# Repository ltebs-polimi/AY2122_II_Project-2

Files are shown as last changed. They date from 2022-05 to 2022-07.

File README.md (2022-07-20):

# ELECTRONIC TECHNOLOGIES AND BIOSENSORS LABORATORY, a.a. 2021/22

# Project 2 - Colombo L., D'Andrea M.

## Objective of the project

The objective of the project is to design and develop a system able to perform glucose monitoring using PSoC 5 as a potentiostat. Internal subdivision of the repository is as following:

- Case: contains the .stl files for the case design and printing
- Documents: contains all the bibliography related to the project and the datasheets of the hardware components
- Group2.cydsn: backup folder containing only the code related to glucose measurement, peripherals not included. **It is not to be intended as the folder of the whole project**
- PCB: contains schematic and board files for the PCB of the device
- Presentations: contains images of the project and final presentation
- Project_design: folder of the actual project
- PYTHON GUI: folder containing python scripts for the GUI
- Regression: folder containing the regression script used to find a calibration line and related images

**To open and run the project, open the Project_ETBL.cywrk file**

## Features implemented

Besides being capable of performing glucose measurements, the device hardware includes:

- RTC (DS3231): for real time tracking
- Bluetooth BR/EDR module (HC-05): for wireless communication
- External battery
- OLED screen (SSD1306 by Adafruit): to visualize data when GUI is not active
- External EEPROM (24LC512 by MicroChip): to store measurements

The assembled device and PCB are in the following images:
<br>

<p align="center">
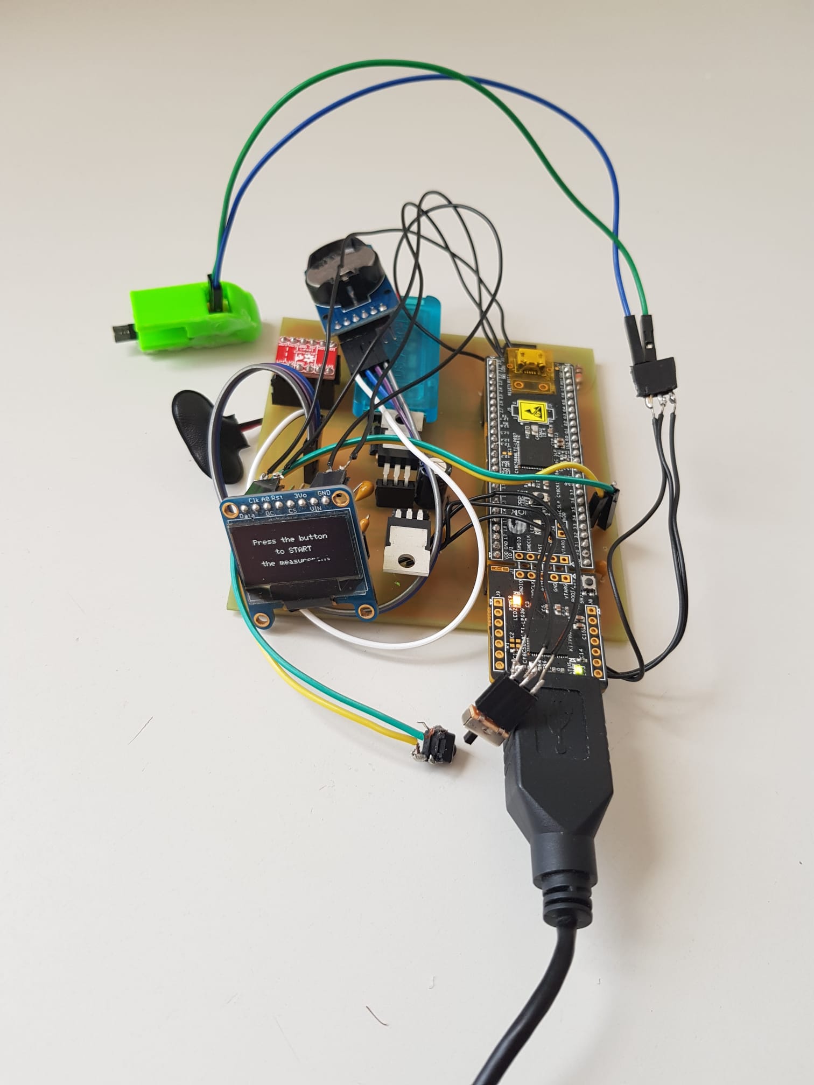
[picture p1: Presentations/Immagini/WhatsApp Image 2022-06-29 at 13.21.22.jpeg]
PCB

</p>
<br><br>

<br>

<p align="center">
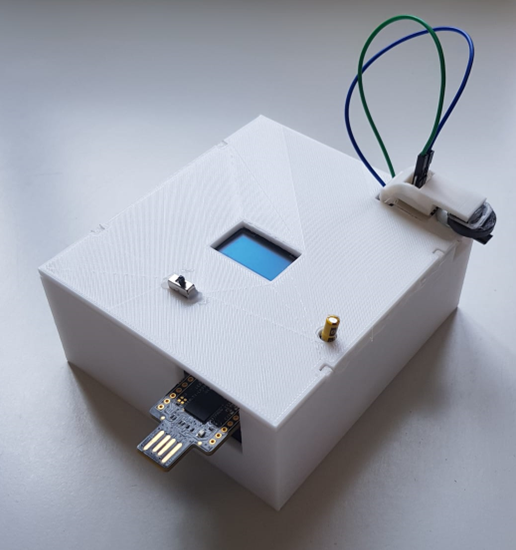
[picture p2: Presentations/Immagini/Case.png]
DEVICE

</p>
<br><br>

## PSoC code
The PSoC code is composed by:

- A global switch case handling the passage between the different OLED screens, up to the "Press the button to START the measurement" screen

- When the hardware button is pressed, the code automatically fetches potential values from the EEPROM and starts and amperometry scan. Basically "adcDacInterrupt" scans
a look-up table and sets the values to the DAC. At the same time the "adcAmpInterrupt" converts the values read by the ADC into current. In the end a glucose 
concentration value is retrieved by means of a proper calibration curve and the result is shown on the OLED screen.

- In case the GUI is started, the code allows to have a connection to the GUI and all the possible commands are managed. Among the different possibilities:
    - cyclic voltammetry (CV): another look up table is scanned by "dacInterrupt" and the "adcInterrupt" convertes the ADC readings into current. These values are sent to the GUI via bluetooth
    - chronoamperometry (CA): same as described before but in this case the current values are sent via bluetooth to the GUI
    - measurements history: measurements which were saved into the EEPROM (date, time and glucose value) at the end of a CA, are sent to the GUI via bluetooth

**see "GUI code" for further details**

## GUI code
The GUI is based on 3 different screens:

- first_screen.py: it allows to select between a user and a clinician

- user_screen.py:
    - Automatic COM port detection by sending a proper command to the PSoC and waiting for the expected answer
    - By pressing the "START MEASUREMENT" button, only a chronoamperometry will be started by sending a proper command to the psoc. The two ISRs needed for the chronoamperometry will be started. Finally the result of the measurement is displayed

- clinician_screen.py: 
    - Automatic COM port detection by sending a proper command to the PSoC and waiting for the expected answer
    - First tab (cyclic voltammetry): it is possible to setup all the required parameters for a cyclic voltammetry. Then it allows to visualize a real-time
    graph by pressing "DRAW"
    - Second tab (chronoamperometry): The clinician can decide to fetch a value of potential from the EEPROM or to start a CA based on the peak of potential identified 
    by the previous cyclic voltammetry. In both cases the real-time graph is shown
    - Third screen (Data visualization): it displays the result of the chronoamperometry scan, in terms of glucose concentration
    - Fourth tab (History): it allows to check the three latest measurements taken by the device. There is also the indication about the date and the time at which the 
    measurements have been taken

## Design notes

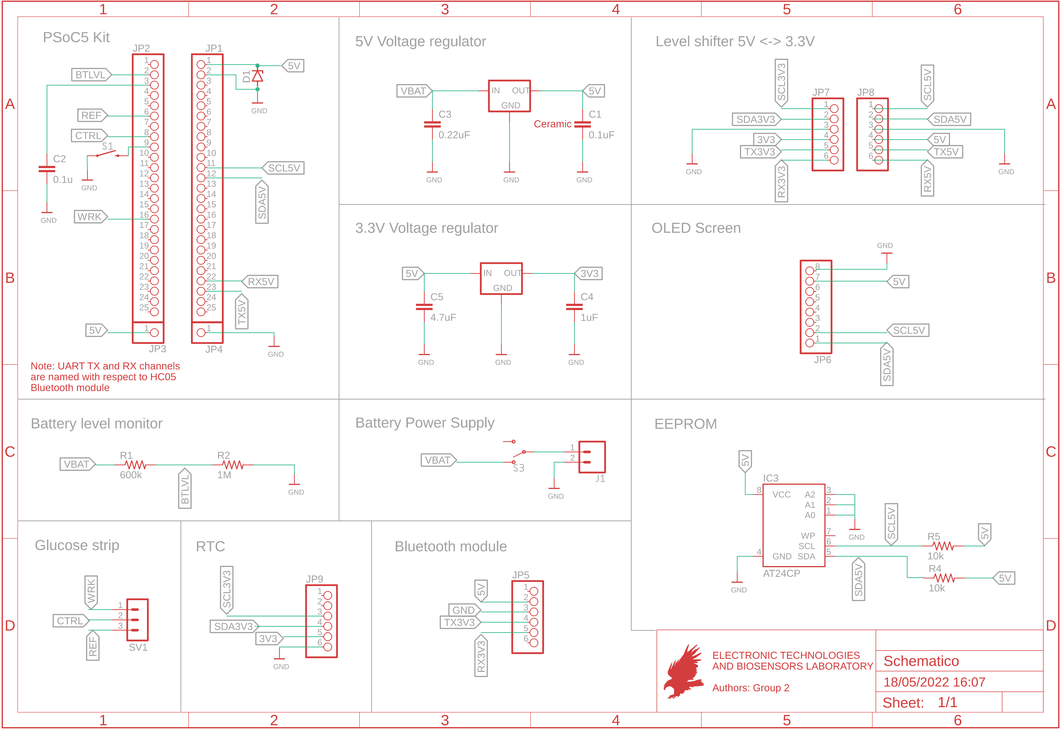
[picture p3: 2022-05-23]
PCB/schematic.png

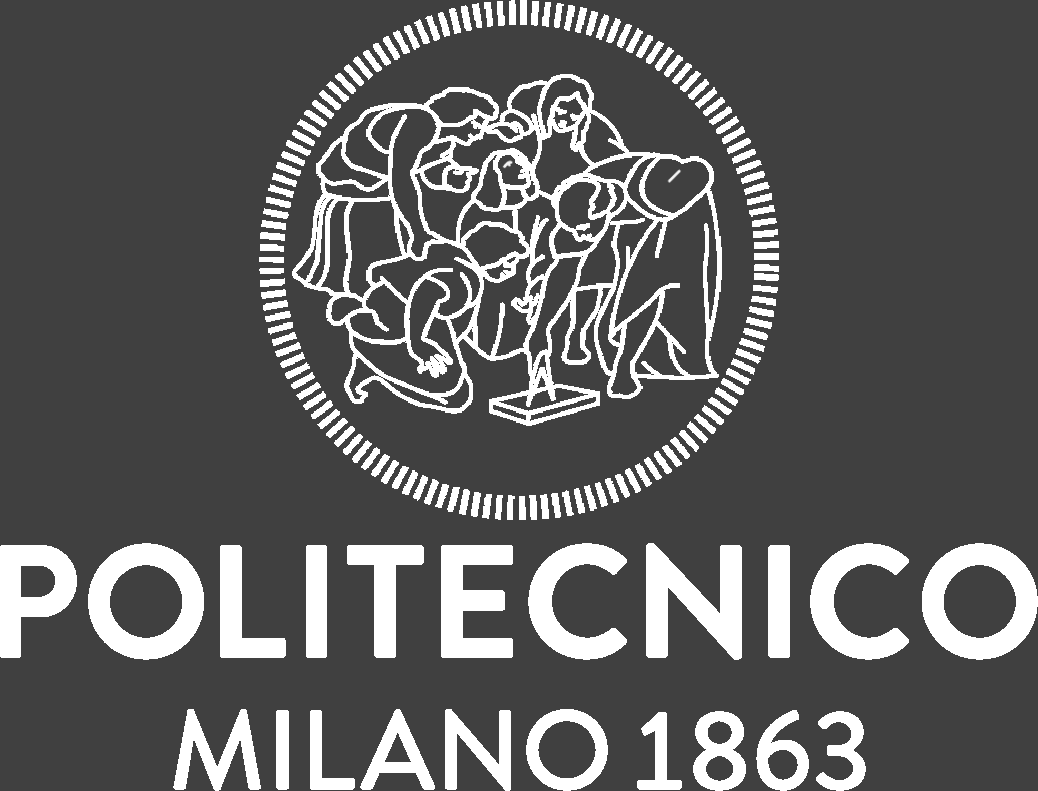
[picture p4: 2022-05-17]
PYTHON GUI/cropped-POLIMI-bianco.png

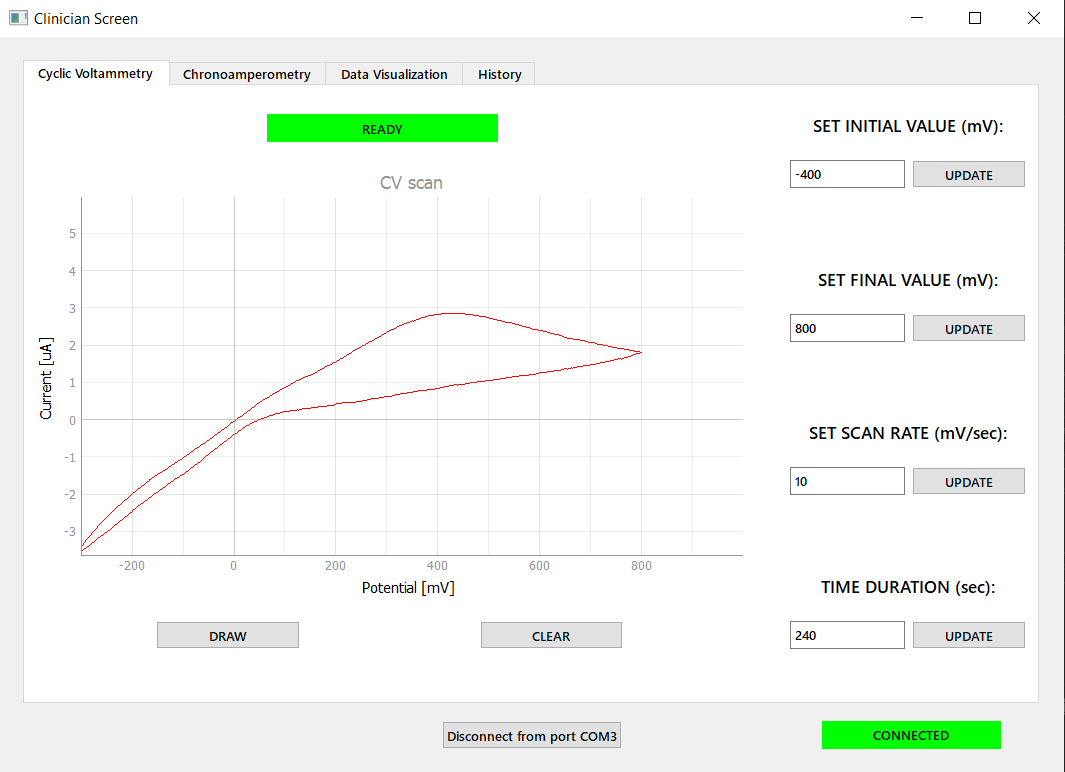
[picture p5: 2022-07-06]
Presentations/Immagini/115-CV.PNG

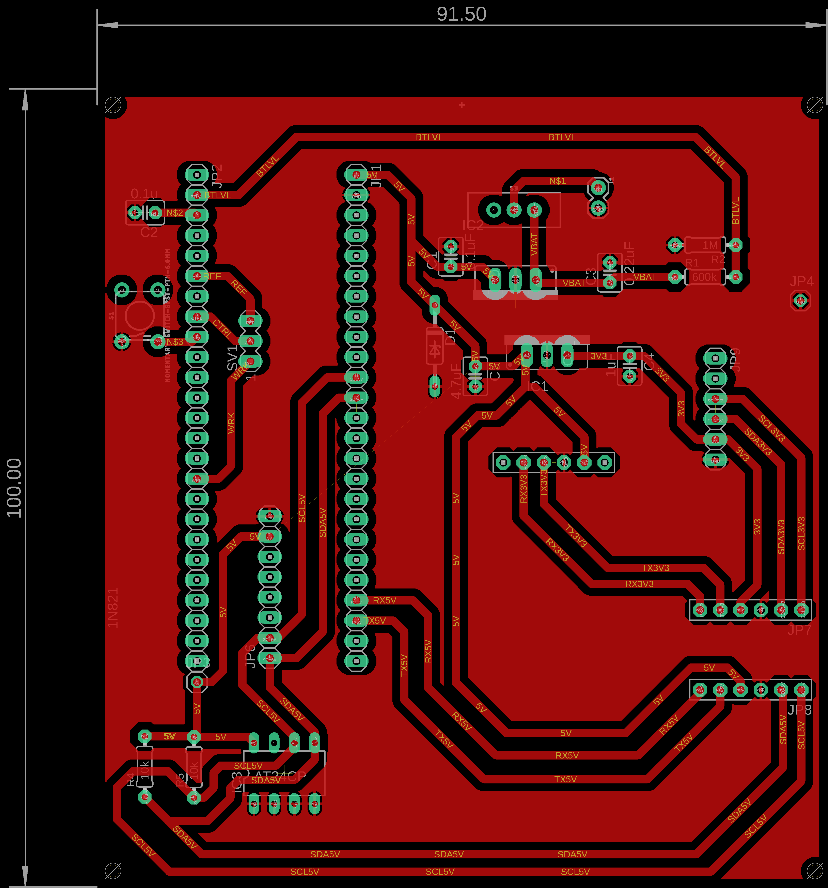
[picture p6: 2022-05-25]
PCB/pcb-1.png

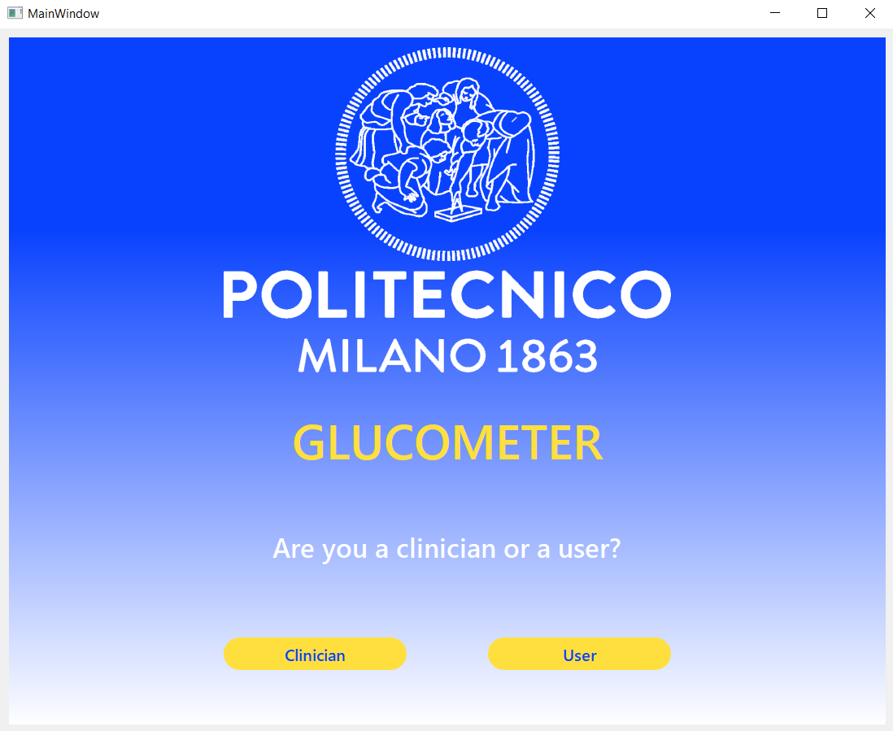
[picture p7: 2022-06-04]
Presentations/Immagini/first_screen.PNG

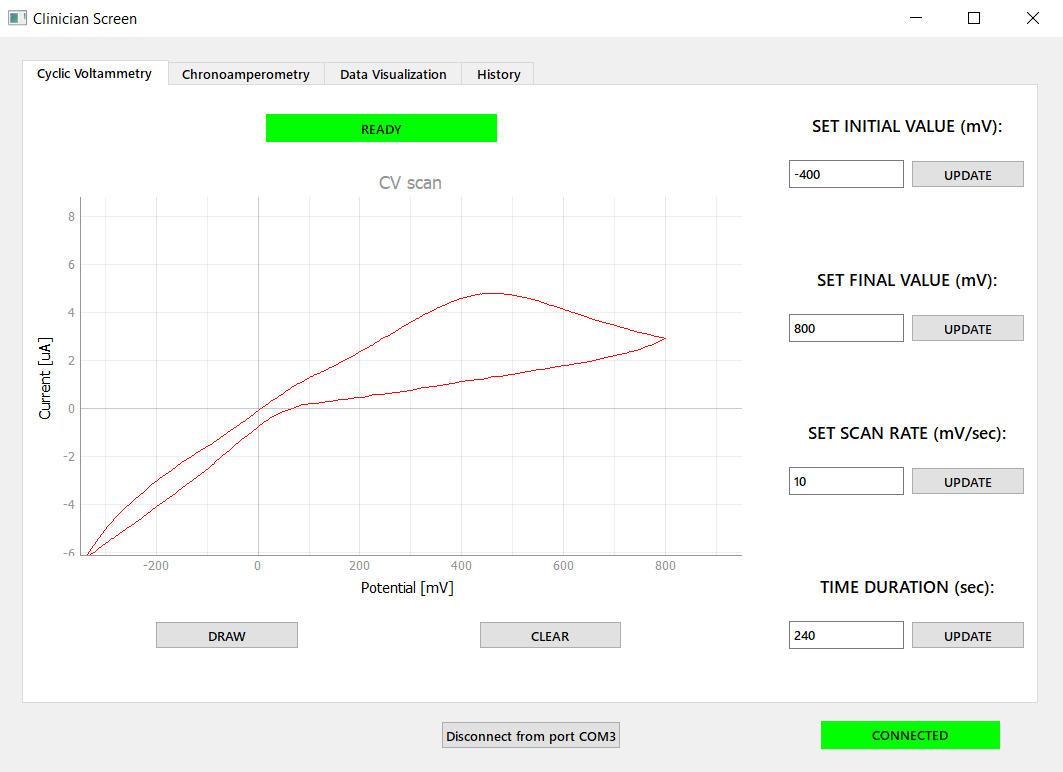
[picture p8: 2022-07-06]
Presentations/Immagini/150-CV.PNG

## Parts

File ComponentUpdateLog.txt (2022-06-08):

Last Modified Date & Time: 06/08/2022 13:05:44

Group2: TopDesign.cysch
	ADC_SigDel [v3.20] to [v3.30]
	isr_adc [v1.70] to [v1.71]
	isr_adcAmp [v1.70] to [v1.71]
	isr_dac [v1.70] to [v1.71]

Project_design: TopDesign.cysch
	ADC_SigDel [v3.20] to [v3.30]
	isr_adc [v1.70] to [v1.71]
	isr_adcAmp [v1.70] to [v1.71]
	isr_dac [v1.70] to [v1.71]

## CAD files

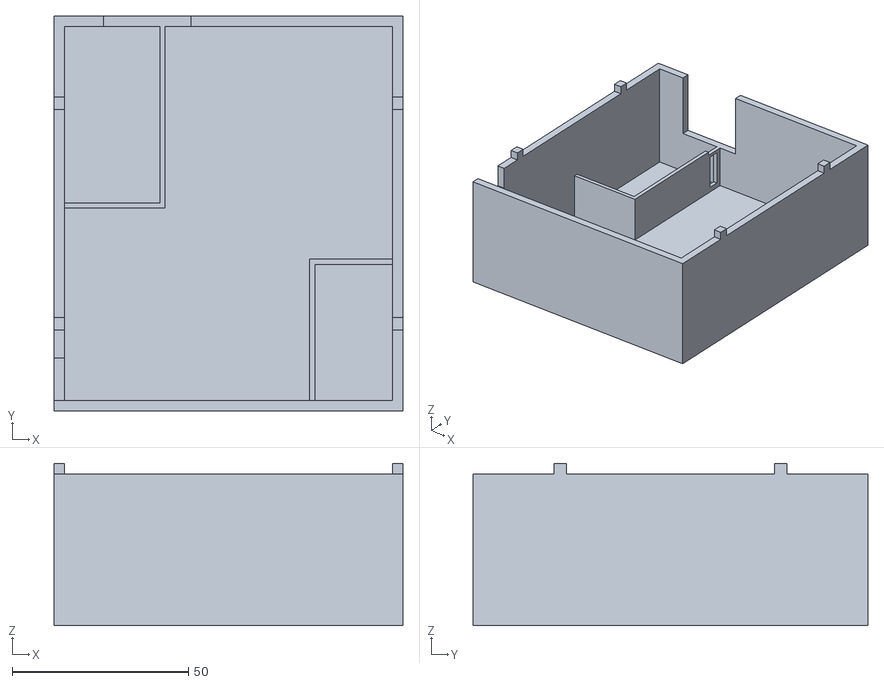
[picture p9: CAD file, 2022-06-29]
Case/Case_ETBL v25.stl
99.0 x 112.0 x 46.0

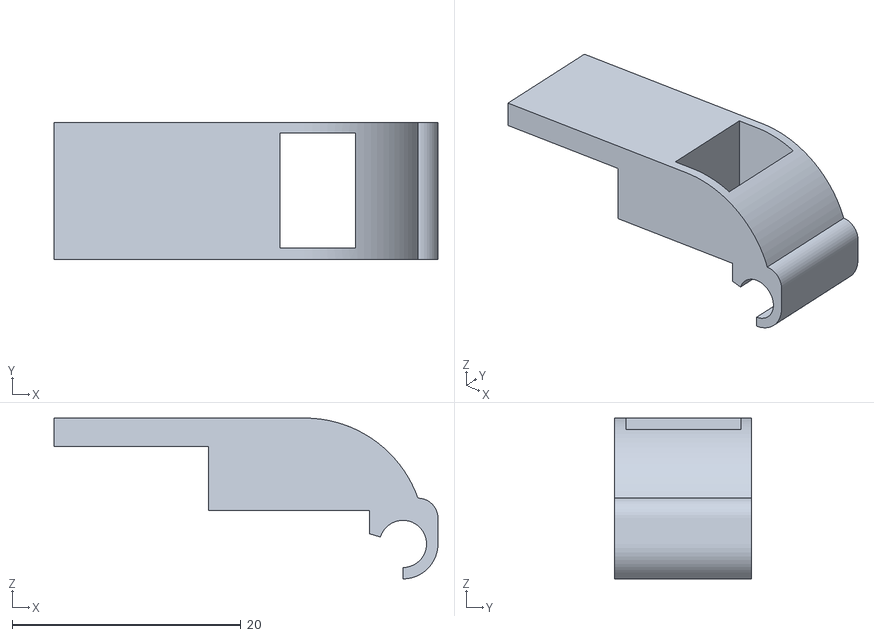
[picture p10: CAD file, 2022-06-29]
Case/Glucometer_clip_top v12.stl
33.6 x 12.0 x 14.1

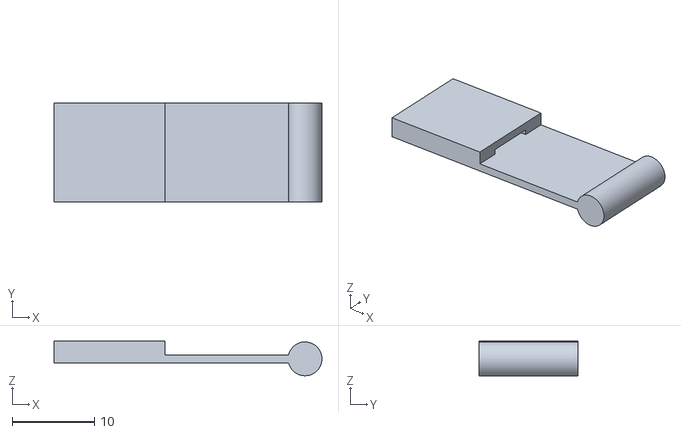
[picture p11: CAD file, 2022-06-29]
Case/Glucometer_clip v12.stl
32.6 x 12.0 x 4.21

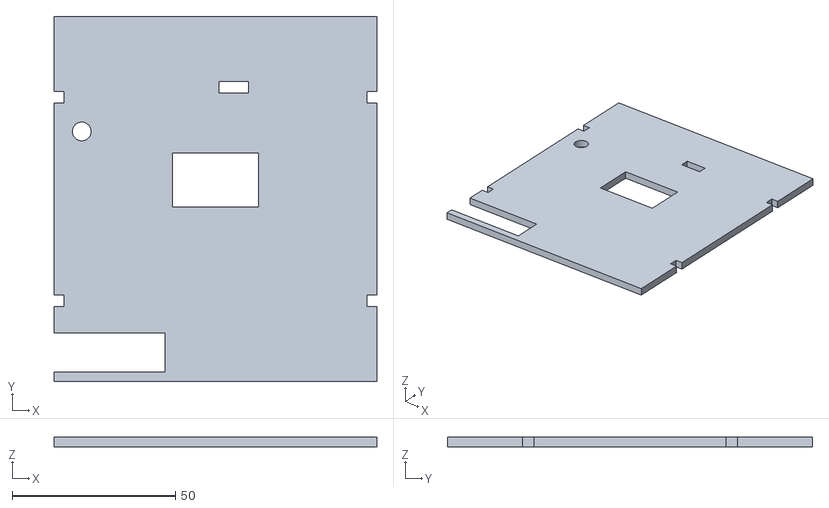
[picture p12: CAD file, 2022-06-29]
Case/Copertura case ETBL v15.stl
99.0 x 112.0 x 3.00

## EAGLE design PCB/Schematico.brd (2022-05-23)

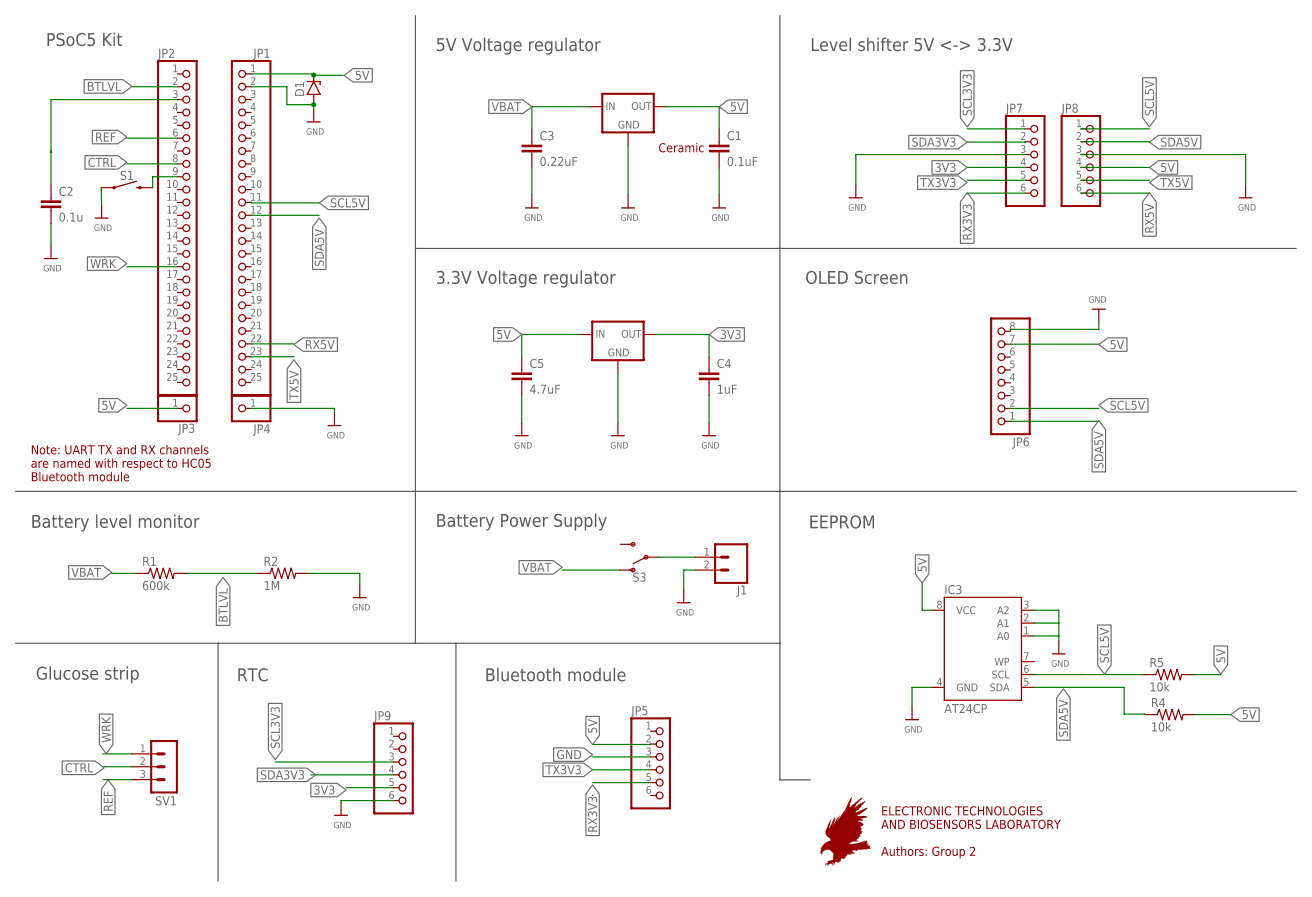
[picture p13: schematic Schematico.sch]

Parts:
C1: 0.1uF; C2.5-3
C2: 0.1u; C2.5-3
C3: 0.22uF; C2.5-3
C4: 1uF; C2.5-3
C5: 4.7uF; C2.5-3
D1: 1N821; DO35Z10
IC1, IC2: 78XXS
IC3: AT24CP; DIL08
J1: CONN_02; 1X02
JP1, JP2: PINHD-1X25; 1X25
JP3, JP4: PINHD-1X1; 1X01
JP5, JP7, JP8: PINHD-1X6B; 1X06-BIG
JP6: PINHD-1X8; 1X08
JP9: PINHD-1X6; 1X06
R1: 600k; 0204/7
R2: 1M; 0204/7
R4, R5: 10k; 0204/7
S1: MOMENTARY-SWITCH-SPST-PTH-6.0MM; TACTILE_SWITCH_PTH_6.0MM
S3: SWITCH-SPDT-PTH-11.6X4.0MM; SWITCH_SPDT_PTH_11.6X4.0MM
SV1: MA03-1

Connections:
3V3: C4.1, IC1.OUT, JP7.4, JP9.5
5V: C1.1, C5.1, D1.C, IC1.IN, IC2.OUT, IC3.8 (VCC), JP1.1, JP3.1, JP5.2, JP6.7, JP8.4, R4.2, R5.2
BTLVL: JP2.2, R1.2, R2.1
CTRL: JP2.8, SV1.2
GND: C1.2, C2.2, C3.2, C4.2, C5.2, D1.A, IC1.GND, IC2.GND, IC3.1 (A0), IC3.2 (A1), IC3.3 (A2), IC3.4 (GND), J1.2, JP1.2, JP4.1, JP5.3, JP6.8, JP7.3, JP8.3, JP9.6, R2.2, S1.1
unnamed: J1.1, S3.2
unnamed: C2.1, JP2.3
unnamed: JP2.9, S1.3 (2)
REF: JP2.6, SV1.3
RX3V3: JP5.5, JP7.6
RX5V: JP1.22, JP8.6
SCL3V3: JP7.1, JP9.3
SCL5V: IC3.6 (SCL), JP1.11, JP6.2, JP8.1, R5.1
SDA3V3: JP7.2, JP9.4
SDA5V: IC3.5 (SDA), JP1.12, JP6.1, JP8.2, R4.1
TX3V3: JP5.4, JP7.5
TX5V: JP1.23, JP8.5
VBAT: C3.1, IC2.IN, R1.1, S3.1 (O)
WRK: JP2.16, SV1.1

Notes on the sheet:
Level shifter 5V <-> 3.3V
OLED Screen
5V Voltage regulator
RTC
EEPROM
PSoC5 Kit
3.3V Voltage regulator
Battery Power Supply
Glucose strip
Bluetooth module
Note: UART TX and RX channels are named with respect to HC05 Bluetooth module
Battery level monitor
ELECTRONIC TECHNOLOGIES AND BIOSENSORS LABORATORY Authors: Group 2
Ceramic

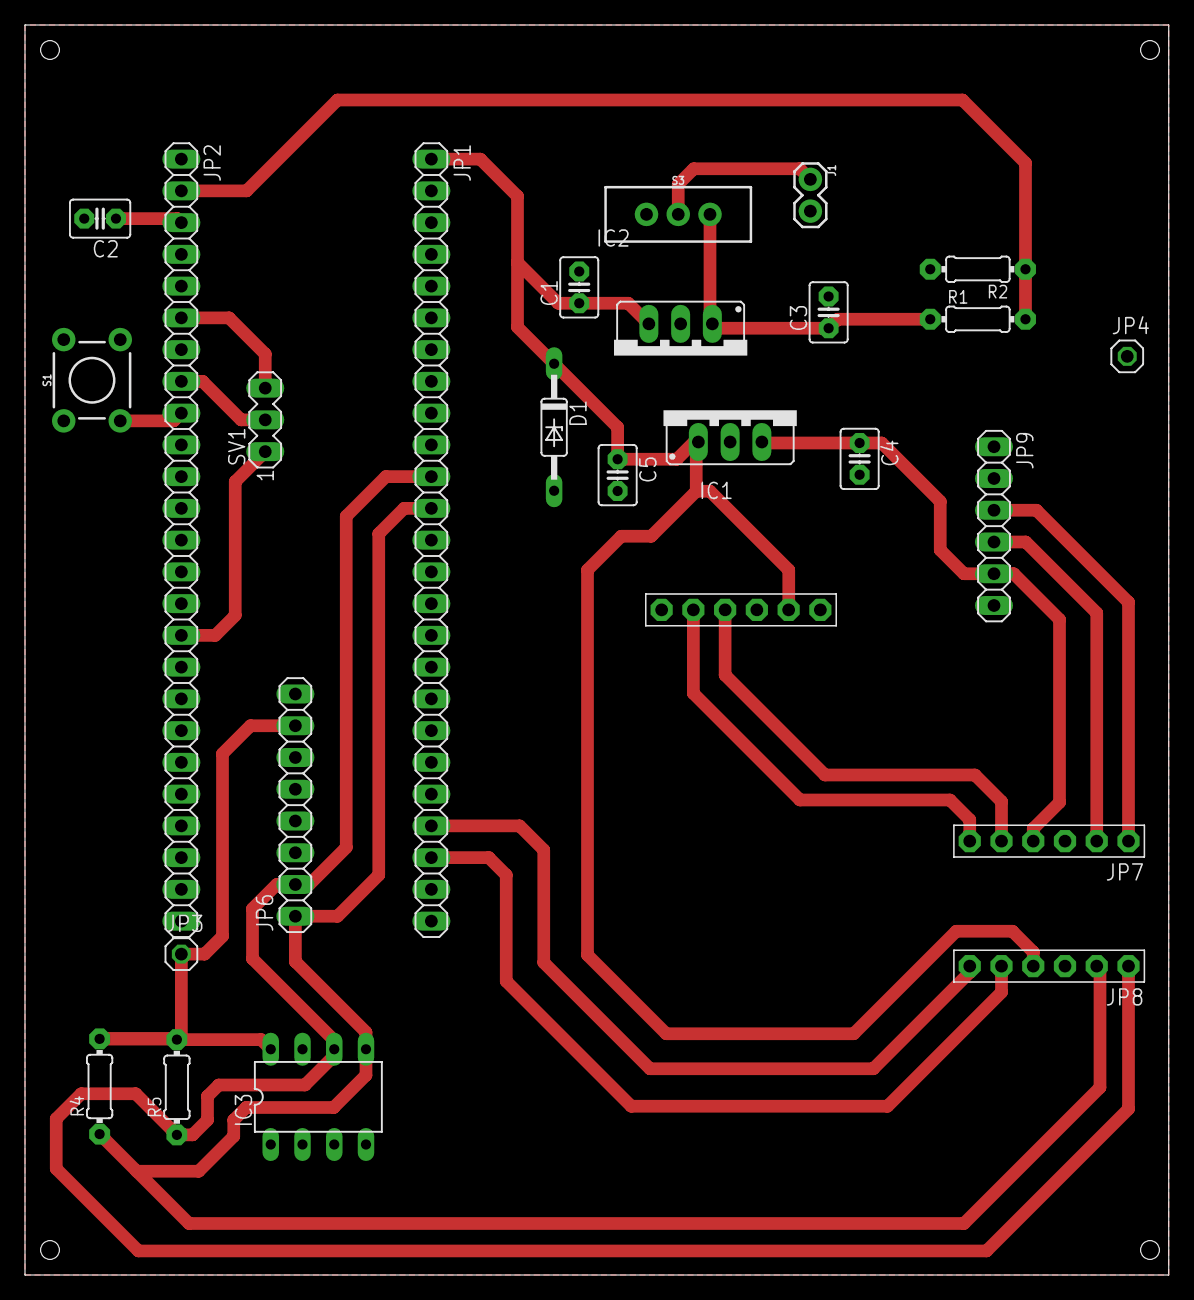
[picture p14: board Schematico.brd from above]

Board: 2 copper layers, 91.5 x 100.0 mm, 26 parts (0 on the bottom side), 19 nets.

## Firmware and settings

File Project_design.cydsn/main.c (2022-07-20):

 /* ========================================================================
 *
 * ELECTRONIC TECHNOLOGIES AND BIOSENSORS LABORATORY
 * Academic year 2021/22, II Semester
 * Final Project
 *
 * Authors: Group 2
 *
 * --------------------------------- MAIN ---------------------------------
 * Main file.
 * ------------------------------------------------------------------------
 * 
 * ========================================================================
*/

//INCLUDES
#include <project.h>
#include <string.h>
#include <stdio.h>
#include "stdlib.h"

#include "OLED_Driver.h"
#include "RTC_Driver.h"
#include "EEPROM_Driver.h"
#include "ErrorCodes.h"
#include "time.h"
#include "DVDAC.h"
#include "Globals.h"
#include "Helper_functions.h"
#include "InterruptRoutines.h"
#include "user_selections.h"

//STATES DEFINE
#define INITIALIZATION 0
#define IDLE 1
#define LOADING 2
#define DISPLAY_MEASUREMENT 3
#define GUI 4
#define AMPEROMETRY_USER 5
#define STALL 6

//GLOBAL READY TO ACCESS
uint8_t seconds = 0;
uint8_t rtc_data_register;
int16 potential_EEPROM=0;


int main(void)
{
    
    CyDelay(1000);
    
    //Global variables initialization
    state = 0;
    power_on = 1;
    battery_level_OLED = 0;
    flag_bluetooth = 0;
    flag_bluetooth_old = 1;
    flag_first_chrono = 1;
    
    current_seconds_old = 0;
    current_minutes_old = 0;
    current_hours_old = 0;
    current_date_old = 0;
    current_month_old = 0;
    current_year_old = 0;
    
    finished_chronoAmp = 0;
    chronoAmp_progress = 0;
    chronoAmp_progress_old = -1;
    
    glucose_concentration = 100;
    glucose_concentration_old = 0;
    
    btlvl_count = 0;
    flag_btlvl_ready = 0;
    lut_index_old = 1;
    
    spacer = 'A';
   
    CyGlobalIntEnable;
    
    //Initialize Interrupt routines variables
    uA_amp = 0.0;
    current_CV = 0.0;
    average_MA_old=0.0;
    average_MA=0.0;
    average_MA_first=0.0;
    potential_max_current=0;
    counter_amperometry = 0;
    first_time=1;
    valore_adc_mv_CV=0;
    valore_adc_mv_AMP=0;
    max_rel=0.0;
    slope_calibration=0.00929;
    intercept_calibration=0.90714;
    
    //Initialize flags values
    Input_Flag=false;
    Command_ready_Flag=false;
    TIA_Calibration_ended_Flag=false;
    CV_ready_Flag=false;
    CV_finished_flag=false;
    AMP_ready_Flag=false;
    Update_scanrate_Flag=false;
    Update_startvalue_Flag=false;
    Update_endvalue_Flag=false;
    Update_timevalue_Flag=false;
    Button_Flag=true;
    flag_GUI_running=false;
    flag_user_measurement=false;
        
    //Communication protocols start
    I2CMASTER_Start();
    UART_DEBUG_Start();
    
    CyDelay(5);
    
    //Peripherals initialization
    display_init(DISPLAY_ADDRESS);
    rtc_init(RTC_ADDRESS);
        
    int len = 0;
    
    /*If you want to setup the RTC, uncomment the following line and insert the needed informations, in order.
      Seconds, Minutes, Hours, Date, Month, Year
      Then run the program, re-comment the line and re-run the program
    */
    //set_RTC(0x40,0x32,0x09,0x06,JULY,Y_2022);
    
    //RTC debug time check via Terminal (if wrong date, see line 125)
    rtc_read_time(RTC_ADDRESS);
    len = snprintf(rtc_content, sizeof(rtc_content), "%d-%d-%d %02d:%02d\n", current_date, 
               current_month, current_year, current_hours, current_minutes);
    UART_DEBUG_PutString(rtc_content);
    
    uint8_t glucose_concentration_from_memory = 0;
    char flag = 0;
    
    //OLED graphics only for main
    const uint8_t GUI_activated[] = {
        0xff, 0xff, 0xff, 0xff, 0xff, 0xff, 0xff, 0xff, 0xff, 0xff, 0xff, 0xff, 0xff, 0xff, 0xff, 0xff, 
        0xff, 0xff, 0xff, 0xff, 0xff, 0xff, 0xff, 0xff, 0xff, 0xff, 0xff, 0xff, 0xff, 0xff, 0xff, 0xff, 
        0xff, 0xff, 0xff, 0xff, 0xff, 0xff, 0xff, 0xff, 0x8f, 0xff, 0xff, 0xff, 0xff, 0xff, 0xff, 0xff, 
        0xff, 0xff, 0xff, 0xff, 0xff, 0xff, 0xff, 0xff, 0x07, 0xff, 0xff, 0xff, 0xff, 0xff, 0xff, 0xff, 
        0xff, 0xff, 0xff, 0xff, 0xff, 0xff, 0xff, 0xfe, 0x03, 0xff, 0xff, 0xff, 0xff, 0xff, 0xff, 0xff, 
        0xff, 0xff, 0xff, 0xff, 0xff, 0xff, 0xff, 0xfc, 0x61, 0xff, 0xff, 0xff, 0xff, 0xff, 0xff, 0xff, 
        0xff, 0xff, 0xff, 0xff, 0xff, 0xff, 0xff, 0xf8, 0x60, 0xff, 0xff, 0xff, 0xff, 0xff, 0xff, 0xff, 
        0xff, 0xff, 0xff, 0xff, 0xff, 0xff, 0xff, 0xf0, 0x60, 0x7f, 0xff, 0xff, 0xff, 0xff, 0xff, 0xff, 
        0xff, 0xff, 0xff, 0xff, 0xff, 0xff, 0xff, 0xe0, 0x60, 0x3f, 0xff, 0xff, 0xff, 0xff, 0xff, 0xff, 
        0xff, 0xff, 0xff, 0xff, 0xff, 0xff, 0xff, 0xc0, 0x60, 0x1f, 0xff, 0xff, 0xff, 0xff, 0xff, 0xff, 
        0xff, 0xff, 0xff, 0xff, 0xff, 0xff, 0xff, 0x80, 0x00, 0x0f, 0xff, 0xff, 0xff, 0xff, 0xff, 0xff, 
        0xff, 0xff, 0xff, 0xff, 0xff, 0xff, 0xff, 0x00, 0x60, 0x0f, 0xff, 0xff, 0xff, 0xff, 0xff, 0xff, 
        0xff, 0xff, 0xff, 0xff, 0xff, 0xff, 0xfe, 0x00, 0x20, 0x03, 0xff, 0xff, 0xff, 0xff, 0xff, 0xff, 
        0xff, 0xff, 0xff, 0xff, 0xff, 0xff, 0xfc, 0x00, 0x00, 0x03, 0xff, 0xff, 0xff, 0xff, 0xff, 0xff, 
        0xff, 0xff, 0xff, 0xff, 0xff, 0xff, 0xff, 0xff, 0xff, 0xff, 0xff, 0xff, 0xff, 0xff, 0xff, 0xff, 
        0xff, 0xff, 0xff, 0xff, 0xff, 0xff, 0xff, 0xff, 0xff, 0xff, 0xff, 0xff, 0xff, 0xff, 0xff, 0xff, 
        0xff, 0xff, 0xff, 0xff, 0xff, 0xff, 0xff, 0xff, 0xff, 0xff, 0xff, 0xff, 0xff, 0xff, 0xff, 0xff, 
        0xff, 0xff, 0xff, 0xff, 0xff, 0xff, 0xff, 0xff, 0xff, 0xff, 0xff, 0xff, 0xff, 0xff, 0xff, 0xff, 
        0xff, 0xff, 0xff, 0xff, 0xff, 0xff, 0xff, 0xff, 0xff, 0xff, 0xff, 0xff, 0xff, 0xff, 0xff, 0xff, 
        0xff, 0xff, 0xff, 0xff, 0xff, 0xff, 0xff, 0xff, 0xff, 0xff, 0xff, 0xff, 0xff, 0xff, 0xff, 0xff, 
        0xff, 0xff, 0xff, 0xff, 0xff, 0xff, 0xff, 0xff, 0xff, 0xff, 0xff, 0xff, 0xff, 0xff, 0xff, 0xff, 
        0xff, 0xff, 0xf8, 0x03, 0xf0, 0x00, 0xf8, 0x18, 0x1f, 0x08, 0x0f, 0x80, 0x03, 0xc0, 0xff, 0xff, 
        0xff, 0xff, 0xfc, 0x71, 0xf8, 0x7e, 0xe3, 0xce, 0x3f, 0xbe, 0x3f, 0x9c, 0x73, 0x1e, 0x7f, 0xff, 
        0xff, 0xff, 0xfc, 0x70, 0xf8, 0x7b, 0xc3, 0xce, 0x3f, 0xbe, 0x3f, 0xbc, 0x7a, 0x1e, 0x7f, 0xff, 
        0xff, 0xff, 0xfc, 0x71, 0xf8, 0x73, 0xe0, 0xfe, 0x3f, 0xbe, 0x3f, 0xfc, 0x7f, 0x07, 0xff, 0xff, 
        0xff, 0xff, 0xfc, 0x07, 0xf8, 0x7b, 0xf8, 0x1e, 0x3f, 0xbe, 0x3f, 0xfc, 0x7f, 0xc0, 0xff, 0xff, 
        0xff, 0xff, 0xfc, 0x63, 0xf8, 0x7f, 0xff, 0x0e, 0x3f, 0xbe, 0x3f, 0xfc, 0x7f, 0xf8, 0x7f, 0xff, 
        0xff, 0xff, 0xfc, 0x71, 0xf8, 0x7e, 0xcf, 0x8e, 0x3f, 0xbe, 0x3f, 0xfc, 0x7e, 0x7c, 0x7f, 0xff, 
        0xff, 0xff, 0xfc, 0x78, 0xf8, 0x7c, 0xc7, 0x1f, 0x1f, 0x7e, 0x3f, 0x7c, 0x7e, 0x38, 0xff, 0xff, 
        0xff, 0xff, 0xf0, 0x1c, 0x00, 0x01, 0xf9, 0xff, 0xe3, 0xf8, 0x00, 0xf0, 0x1f, 0xcf, 0xff, 0xff, 
        0xff, 0xff, 0xff, 0xff, 0xff, 0xff, 0xff, 0xff, 0xff, 0xff, 0xff, 0xff, 0xff, 0xff, 0xff, 0xff, 
        0xff, 0xff, 0xff, 0xff, 0xff, 0xff, 0xff, 0xff, 0xff, 0xff, 0xff, 0xff, 0xff, 0xff, 0xff, 0xff, 
        0xff, 0xff, 0xff, 0xff, 0xff, 0xff, 0xff, 0xff, 0xff, 0xff, 0xff, 0xff, 0xff, 0xff, 0xff, 0xff, 
        0xff, 0xff, 0xff, 0xff, 0xff, 0xff, 0xff, 0xff, 0xff, 0xff, 0xff, 0xff, 0xff, 0xff, 0xff, 0xff, 
        0xff, 0xff, 0xff, 0xff, 0xff, 0xff, 0xff, 0xff, 0xff, 0xff, 0xff, 0xff, 0xff, 0xff, 0xff, 0xff, 
        0xff, 0xff, 0xff, 0xff, 0xff, 0xff, 0xff, 0xff, 0xff, 0xff, 0xff, 0xff, 0xff, 0xff, 0xff, 0xff, 
        0xff, 0xff, 0xff, 0xfe, 0x38, 0xfc, 0x3f, 0xbf, 0xfc, 0x78, 0x78, 0x7f, 0x7c, 0x7f, 0xff, 0xff, 
        0xff, 0xff, 0xff, 0xf8, 0xfe, 0x3c, 0x1f, 0xbf, 0xf1, 0xfe, 0x78, 0x7f, 0x7c, 0x7f, 0xff, 0xff, 
        0xff, 0xff, 0xff, 0xf1, 0xfe, 0x3d, 0x87, 0xbf, 0xe3, 0xff, 0x78, 0x7f, 0x7c, 0x7f, 0xff, 0xff, 
        0xff, 0xff, 0xff, 0xf1, 0xfe, 0x1d, 0xe3, 0xbf, 0xe3, 0xff, 0xf8, 0x7f, 0x7c, 0x7f, 0xff, 0xff, 
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
    };
    
    uint32_t rval;
    char message[100] = {'\0'};
    
    //display_clear();
    UART_DEBUG_PutString("\r\n**************\r\n");
    UART_DEBUG_PutString("** I2C Scan **\r\n");
    UART_DEBUG_PutString("**************\r\n");
    
    CyDelay(10);
    
    UART_DEBUG_PutString("\n\n   ");
	for(uint8_t i = 0; i<0x10; i++)
	{
        sprintf(message, "%02X ", i);
		UART_DEBUG_PutString(message);
	}
 
    
    // SCAN the I2C BUS for slaves
	for( uint8_t i2caddress = 0; i2caddress < 0x80; i2caddress++ ) {
        
		if(i2caddress % 0x10 == 0 ) {
            sprintf(message, "\n%02X ", i2caddress);
		    UART_DEBUG_PutString(message);
        }
 
		rval = I2CMASTER_MasterSendStart(i2caddress, I2CMASTER_WRITE_XFER_MODE);
        
        if( rval == I2CMASTER_MSTR_NO_ERROR ) // If you get ACK then print the address
		{
            sprintf(message, "%02X ", i2caddress);
		    UART_DEBUG_PutString(message);
		}
		else //  Otherwise print a --
		{
		    UART_DEBUG_PutString("-- ");
		}
        I2CMASTER_MasterSendStop();
	}
	UART_DEBUG_PutString("\n\n");

    
    // PSOC Variables initialization
    lut_length=5000; // how long the look up table is,initialize large so when starting isr the ending doesn't get triggered
    command_lenght = 0;
    
    /* Place your initialization/startup code here (e.g. MyInst_Start()) */
    helper_HardwareSetup();  //user-defined function to initialize the HW 
    
    ADC_SigDel_SelectConfiguration(1, DO_NOT_RESTART_ADC); // select the configuration to be used for the ADC (2 possible configurations --> SERVONO ???)

    
    //Start the UART (used by the BT) and the corresponding isr
    UART_BLT_Start();

    
    //Initialize all interrupts
    isr_dac_StartEx(dacInterrupt);
    isr_dac_Disable();  
    
    isr_adc_StartEx(adcInterrupt);
    isr_adc_Disable();
    
    isr_adcAmp_StartEx(adcAmpInterrupt);
    isr_adcAmp_Disable();
    
    isr_dac_AMP_StartEx(adcDacInterrupt);
    isr_dac_AMP_Disable();
    
    //isr_timer_StartEx(ISR_battery);
    
    TIA_SetResFB(TIA_RES_FEEDBACK_20K); //A 20KOhm feedback resistor is chosen for the TIA
    
    //Fetch of previously saved EEPROM last saved value address
    eeprom_current_address = get_eeprom_current_address();
    
    //n_samples fetch
    n_measures = get_n_measures();
    
    //Terminal print debugs. If errors or to reset the memory, see line 294 and comment from line 282 to 285 included
    len = snprintf(rtc_content, sizeof(rtc_content), "N_MEASURES: %d\r\n\n", n_measures);
    UART_DEBUG_PutString(rtc_content);
    
    len = snprintf(rtc_content, sizeof(rtc_content), "EEPROM current address: %d\r\n\n", eeprom_current_address);
    UART_DEBUG_PutString(rtc_content);
    
    //TO RESET MEMORY, UNCOMMENT LINES BELOW
    /*
    n_measures = 0;
    ErrorCode error;
    error = EEPROM_WriteRegister(EEPROM_ADDRESS, 0x0004, n_measures); 
    if(error == ERROR) {
        UART_DEBUG_PutString("\nError in saving number of measurements in EEPROM memory\r\n");
    }
    CyDelay(50);
    
    error = EEPROM_WriteRegister(EEPROM_ADDRESS, 0x0000, 0x00); 
    if(error == ERROR) {
        UART_DEBUG_PutString("\nError in saving EEPROM initialization H in EEPROM memory\r\n");
    }
    CyDelay(50);
    
    error = EEPROM_WriteRegister(EEPROM_ADDRESS, 0x0001, 0x06); 
    if(error == ERROR) {
        UART_DEBUG_PutString("\nError in saving EEPROM initialization L in EEPROM memory\r\n");
    }
    
    CyDelay(50);*/
    
    //TO WRITE POTENTIAL VALUE TO EEPROM
    potential_max_current = 2200;
    save_CV_result();
    len = snprintf(rtc_content, sizeof(rtc_content), "potential saved: %d", potential_max_current);
    UART_DEBUG_PutString(rtc_content);
    

    while(1)
    {
        //CyWdtClear(); //The watchdog must be cleared using the CyWdtClear() function before three ticks of the watchdog timer occur
        
        //OUTER SWITCH CASE
        switch(state) {
            
            //STALL: Measurement done, history open. The PSoC does not do anything
            case STALL:    
            break;
            
            //INITIALIATION: OLED is started and also peripherals are checked
            case INITIALIZATION:
                OLED_welcome_screen();
                
                //Serial terminal debug
                rtc_read_time(RTC_ADDRESS);
                len = snprintf(rtc_content, sizeof(rtc_content), "Secondi: %d\r\n", current_seconds);
                UART_DEBUG_PutString(rtc_content);
                len = snprintf(rtc_content, sizeof(rtc_content), "Minuti: %d\r\n", current_minutes);
                UART_DEBUG_PutString(rtc_content);
                len = snprintf(rtc_content, sizeof(rtc_content), "Ore: %d\r\n", current_hours);
                UART_DEBUG_PutString(rtc_content);
                len = snprintf(rtc_content, sizeof(rtc_content), "Giorno: %d\r\n", current_date);
                UART_DEBUG_PutString(rtc_content);
                len = snprintf(rtc_content, sizeof(rtc_content), "Mese: %d\r\n", current_month);
                UART_DEBUG_PutString(rtc_content);
                len = snprintf(rtc_content, sizeof(rtc_content), "Anno: %d\r\n\n", current_year);
                UART_DEBUG_PutString(rtc_content);
                
                current_year8 = 0xFF & (current_year - 2000);
                
                len = snprintf(rtc_content, sizeof(rtc_content), "%d-%d-%d %02d:%02d:%02d\n", current_date, 
                               current_month, current_year, current_hours, current_minutes, current_seconds);
                UART_DEBUG_PutString(rtc_content);
                
                /*if(flag == 0) {
                    flag = 1;
                    save_current_measurement(glucose_concentration);
                    glucose_concentration_from_memory = get_measurement_from_memory(eeprom_current_address - 8);
                }*/
                
                state = IDLE;

            break;
            
            //IDLE: the microcontroller awaits if the user is connecting to a GUI or presses the 
            //button to use the OLED screen
            case IDLE:
                button_state = Pin_Button_Read();
                //len = snprintf(message, sizeof(message), "%d\n", button_state);
                //UART_DEBUG_PutString(message);
                if(button_state==0) {
                    state = LOADING;
                    Button_Flag = false;
                    display_clear();                    
                }
                
                
                if (UART_BLT_GetRxBufferSize() > 0 && Command_ready_Flag==false) // Continuously check if something is received via UART
                {
                    Input_Flag=true;
                    uint8_t received_char = UART_BLT_GetChar();
                    command[command_lenght] = received_char;                 
                    command_lenght += 1;
                    
                }
                
                if(Input_Flag==true && UART_BLT_GetRxBufferSize()==0){

                    if (command[command_lenght-1]=='z') //This is necessary in order to understand if the message has ended (or use a tail as an alternative)
                    {   

                        Input_Flag=false;
                        Command_ready_Flag=true;
                        display_clear();
                        display_update();
                        rtx_drawBitmap(0, 0, GUI_activated, 128, 64, BLACK, WHITE);
                        display_update();
                        state=GUI;
                        flag_GUI_running=true;
                        len= snprintf(str, sizeof(str), "comando ricevuto in case IDLE: %c\r\n", command[0]);
                        UART_DEBUG_PutString(str); 
                        
                        
                    }
                }
                
                
            
            break;
               
            //LOADING: if the user is not connected to a GUI, this state displays a loading bar while
            //chronoamperometry procedure is performed
            case LOADING:
                
                if(flag_first_chrono == 1)
                {
                    //fetch from EEPROM the needed data
                    potential_EEPROM = get_CV_result();                
                    
                    user_chrono_lut_maker(2000);   // Create a look up table for chronoamperometry            
                    user_run_amperometry();
                    flag_first_chrono = 0;
                }
                
                if(!finished_chronoAmp)
                {
                    /*if(lut_index_old!=lut_index){
                        OLED_loading();
                    }*/
                } else {
                    state = DISPLAY_MEASUREMENT;
                    flag_first_chrono = 1;
                }
                
            break;
            
            //DISPLAY_MEASUREMENT: on the OLED, glucose concentration value is displayed
            case DISPLAY_MEASUREMENT:
                finished_chronoAmp = 0;
                if(power_on){
                    power_on = 0;
                    display_battery_level(battery_level_OLED);

                }
                
                rtc_set_time();
                
                display_bluetooth_connection(flag_bluetooth);
                
                OLED_display_glucose();
                
                OLED_display_indicator();
            
                
                button_state = Pin_Button_Read();
                len = snprintf(message, sizeof(message), "%d\n", button_state);
                UART_DEBUG_PutString(message);
            
            break;
               
        
            //GUI: user connected to a GUI (OLED bypassed)
            case GUI:
                
                
                if (UART_BLT_GetRxBufferSize() > 0 && Command_ready_Flag==false) // Continuously check if something is received via UART
                {
                    Input_Flag=true;
                    uint8_t received_char = UART_BLT_GetChar();
                    command[command_lenght] = received_char;
                    command_lenght += 1;
                    
                }
                
                if(Input_Flag==true && UART_BLT_GetRxBufferSize()==0){

                    if (command[command_lenght-1]=='z') //This is necessary in order to understand if the message has ended (or use a tail as an alternative)
                    {   

                        Input_Flag=false;
                        Command_ready_Flag=true;
                        
                    }
                }
                
                if(CV_finished_flag==true){
                    command[0]='I';
                    CV_finished_flag=false;
                    Command_ready_Flag=true;
                }

                
                //Check if something has been received by the UART 
                if (Command_ready_Flag == true && Button_Flag==true) {  
                    
                    //INNER SWITCH CASE
                    //Switch case based on the first character that is received
                    switch (command[0]) { 
                        
                    //CONNECT_TO_COM_PORT: checks if device is connected to COM port via GUI
                    case CONNECT_TO_COM_PORT: // 'A' Connect to the BT COM port
                        
                        len= snprintf(str, sizeof(str), "comando ricevuto in case GUI: %c\r\n", command[0]);
                        UART_DEBUG_PutString(str);
                        
                        sprintf(DataBuffer, "Glucose $$$");
                        UART_BLT_PutString(DataBuffer);
                        UART_DEBUG_PutString(DataBuffer);
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

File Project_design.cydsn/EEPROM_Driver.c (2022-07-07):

/* ========================================================================
 *
 * ELECTRONIC TECHNOLOGIES AND BIOSENSORS LABORATORY
 * Academic year 2021/22, II Semester
 * Final Project
 *
 * Authors: Group 2
 *
 * ----------------------- EEPROM Driver (source) -------------------------
 * Implementation of the function defined in the EEPROM Driver header
 * ------------------------------------------------------------------------
 * 
 * ========================================================================
*/

#include <project.h>
#include <stdlib.h>
#include <math.h>
#include <stdio.h>
#include "EEPROM_Driver.h"

/*------------------------------------------------------------------------
*                       FUNCTIONS IMPLEMENTATION
-------------------------------------------------------------------------*/
/*  EEPROM READ REGISTER
*   \brief: Function that reads slave register content
*   \Parameters:
*       @param device_address: 8-bit slave device address
*       @param register_address: 16-bit address of the register where content is stored
*       @param data: pointer to array where to store read value
*   \Return: error (if reading is successfull or not)
*/
ErrorCode EEPROM_ReadRegister(uint8_t device_address, uint16_t register_address, uint8_t* data){
     
    //The function returns an ACK or NACK.
    uint8_t error = I2CMASTER_MasterSendStart(device_address, I2CMASTER_WRITE_XFER_MODE);                                        
    if (error == I2CMASTER_MSTR_NO_ERROR)
    {
        //Write the register address to be read. HIGH byte first, LOW byte then
        uint8_t MSB = (register_address & 0xFF00)>>8;
        uint8_t LSB = register_address & 0x00FF;
        error = I2CMASTER_MasterWriteByte(MSB);
        error = I2CMASTER_MasterWriteByte(LSB);
        if (error == I2CMASTER_MSTR_NO_ERROR)
        {
            
            error = I2CMASTER_MasterSendRestart(device_address, I2CMASTER_READ_XFER_MODE);
            if (error == I2CMASTER_MSTR_NO_ERROR)
            {
                *data = I2CMASTER_MasterReadByte(I2CMASTER_NAK_DATA); //The NACK is needed otherwise the I2C keeps reading
            }
        }
    }

    I2CMASTER_MasterSendStop();

    return error ? ERROR : NO_ERROR;
}

/*  EEPROM WRITE REGISTER
*   \brief: Function that sets slave register content
*   \Parameters:
*       @param device_address: 8-bit slave device address
*       @param register_address: 16-bit address of the register where content has to be written
*       @param data: pointer to array containing values to be written
*   \Return: error (if writing is successfull or not)
*/
ErrorCode EEPROM_WriteRegister(uint8_t device_address, uint16_t register_address, uint8_t data){   
    
    uint8_t error = I2CMASTER_MasterSendStart(device_address, I2CMASTER_WRITE_XFER_MODE);
    
    if (error == I2CMASTER_MSTR_NO_ERROR)
    {
        // Write Register Address HIGH byte first, LOW byte then
        uint8_t MSB = (register_address & 0xFF00)>>8;
        uint8_t LSB = register_address & 0x00FF;
        error = I2CMASTER_MasterWriteByte(MSB);
        error = I2CMASTER_MasterWriteByte(LSB);
        if (error == I2CMASTER_MSTR_NO_ERROR)
        {
            // Write data byte content
            error = I2CMASTER_MasterWriteByte(data);
        }
    }

    I2CMASTER_MasterSendStop();

    return error ? ERROR : NO_ERROR;
}

/*  EEPROM SAVE CURRENT MEASUREMENT
*   \brief: Function that saves the timestamp of the measurement and 
*           the measurement itself
*   \Parameters:
*       @param glucose concentration: glucose concentration value
*   \Return: NONE
*/
void save_current_measurement(uint8_t glucose_concentration) {
    
    ErrorCode error;
    
    error = EEPROM_WriteRegister(EEPROM_ADDRESS, eeprom_current_address, current_minutes);
    if(error == ERROR) {
        UART_DEBUG_PutString("\nError in saving minutes in EEPROM memory\r\n");
    }
    CyDelay(50);
    
    error = EEPROM_WriteRegister(EEPROM_ADDRESS, eeprom_current_address + 1, current_hours);
    if(error == ERROR) {
        UART_DEBUG_PutString("\nError in saving hours in EEPROM memory\r\n");
    }
    CyDelay(50);
    
    error = EEPROM_WriteRegister(EEPROM_ADDRESS, eeprom_current_address + 2, current_date);
    if(error == ERROR) {
        UART_DEBUG_PutString("\nError in saving date in EEPROM memory\r\n");
    }
    CyDelay(50);
    
    error = EEPROM_WriteRegister(EEPROM_ADDRESS, eeprom_current_address + 3, current_month);
    if(error == ERROR) {
        UART_DEBUG_PutString("\nError in saving month in EEPROM memory\r\n");
    }
    CyDelay(50);
    
    error = EEPROM_WriteRegister(EEPROM_ADDRESS, eeprom_current_address + 4, current_year8);
    if(error == ERROR) {
        UART_DEBUG_PutString("\nError in saving year in EEPROM memory\r\n");
    }
    CyDelay(50);
    
    error = EEPROM_WriteRegister(EEPROM_ADDRESS, eeprom_current_address + 5, glucose_concentration); 
    if(error == ERROR) {
        UART_DEBUG_PutString("\nError in saving glucose data in EEPROM memory\r\n");
    }
    CyDelay(50);
    
    /*error = EEPROM_WriteRegister(EEPROM_ADDRESS, eeprom_current_address + 6, spacer); 
    if(error == ERROR) {
        UART_DEBUG_PutString("\nError in saving spacer in EEPROM memory\r\n");
    }
    CyDelay(50);*/
    
    eeprom_current_address += 6;
    
    
    //EEPROM current address saving
    error = EEPROM_WriteRegister(EEPROM_ADDRESS, 0x0000, eeprom_current_address >> 8); 
    if(error == ERROR) {
        UART_DEBUG_PutString("\nError in saving EEPROM_H address in EEPROM memory\r\n");
    }
    CyDelay(50);
    
    error = EEPROM_WriteRegister(EEPROM_ADDRESS, 0x0001, eeprom_current_address & 0xFF); 
    if(error == ERROR) {
        UART_DEBUG_PutString("\nError in saving EEPROM_L address in EEPROM memory\r\n");
    }
    CyDelay(50);
    
    //Saving number of measures
    n_measures++;
    error = EEPROM_WriteRegister(EEPROM_ADDRESS, 0x0004, n_measures); 
    if(error == ERROR) {
        UART_DEBUG_PutString("\nError in saving number of measurements in EEPROM memory\r\n");
    }
    CyDelay(50);
    
    
    error = EEPROM_WriteRegister(EEPROM_ADDRESS, 0x0005, 255); 
    if(error == ERROR) {
        UART_DEBUG_PutString("\nError in saving spacer of measurements in EEPROM memory\r\n");
    }
    CyDelay(50);
}
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

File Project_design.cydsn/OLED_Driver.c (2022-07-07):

/* ========================================================================
 *
 * ELECTRONIC TECHNOLOGIES AND BIOSENSORS LABORATORY
 * Academic year 2021/22, II Semester
 * Final Project
 *
 * Authors: Group 2
 *
 * ------------------------ OLED Driver (source) --------------------------
 * This file contains functions declared in the OLED header file 
 * implementation. They are divided into core functions to have a working
 * OLED and graphic functions to display things.
 * ------------------------------------------------------------------------
 * 
 * ========================================================================
*/

#include <project.h>
#include <stdlib.h>

#include "font.h"
#include "OLED_Driver.h"
#include "RTC_Driver.h"

/*------------------------------------------------------------------------
*                        OLED DISPLAY REGISTERS
-------------------------------------------------------------------------*/
// DEVICE ADDRESS
#define DISPLAY_ADDRESS                 0x3D    //It can be also 0x3C

// DISPLAY DIMENSIONS
#define DISPLAY_WIDTH                    128
#define DISPLAY_HEIGHT                   64

// FUNDAMENTAL COMMANDS
#define DISPLAY_ON                      0xAF
#define DISPLAY_RESET                   0x7F
#define DISPLAY_CONTRAST                0x81    //Followed by 0xNN for contrast level (value between 0 and 255)
#define DISPLAY_OFF                     0xAE

#define DISPLAY_ALL_ON_RESUME           0xA4    //RAM content displayed
#define DISPLAY_ALL_ON                  0xA5    //Display all white

#define DISPLAY_NORMAL                  0xA6
#define DISPLAY_INVERSE                 0xA7

// ADDRESSING SETTING COMMANDS
#define DISPLAY_LOWER_NIBBLE            0x00    //Followed by 0x0F
#define DISPLAY_UPPER_NIBBLE            0x10    //Followed by 0x1F
#define DISPLAY_SET_MEMORY              0x20    //Followed by: 00b Horizontal addressing, 01b Vertical addressing, 10b Page addressing
#define DISPLAY_SET_MEMORY_HORIZONTAL   0x00
#define DISPLAY_SET_MEMORY_VERTICAL     0x01
#define DISPLAY_SET_MEMORY_PAGE         0x02
#define DISPLAY_SET_COLUMN_ADDR         0x21    //2 bytes param 0-127 for start and 0-127 for end addresses
#define DISPLAY_SET_PAGE_ADDR           0x22    //2 bytes param 0-7 for start and 0-7 for end addresses

// HARDWARE SETTING COMMANDS
#define DISPLAY_START_LINE              0x40   
#define DISPLAY_SEGREMAP                0xA0    //Segment to column address 0
#define DISPLAY_MULTIPLEX               0xA8
#define DISPLAY_COM_OUTPUT              0xC0    //From COM0 to COM(N-1)
#define DISPLAY_COM_OUTPUT_INV          0xC8    //From COM(N-1) to COM0
#define DISPLAY_COM_PINS                0xDA
#define DISPLAY_OFFSET                  0xD3
#define DISPLAY_SET_COM                 0xDB

// TIMING SETTINGS
//Non so se serva mettere il refresh rate ecc
#define DISPLAY_PRECHARGE               0xD9
#define DISPLAY_CLOCKDIV                0xD5

// CHARGE PUMP SETTINGS
#define DISPLAY_CHARGEPUMP              0x8D
#define DISPLAY_CHARGEPUMP_ON           0x14
#define DISPLAY_CHARGEPUMP_OFF          0x10

// I2C TRANSFER RESULT STATUS
#define TRANSFER_CMPLT                  0x00u
#define TRANSFER_ERROR                  0xFFu

/*------------------------------------------------------------------------
*                         STATIC VARIABLES
-------------------------------------------------------------------------*/
static uint8_t oled_i2c_address;
static uint8_t DISPLAY_buffer[DISPLAY_HEIGHT * DISPLAY_WIDTH / 8 + 1] = {0x40};     //Dimension increased by 1 with respect to pixel number to include 0x40 to submit data in position [0]
static uint8_t* display_buf = DISPLAY_buffer+1;                                     //Pointer to next memory cell
static uint16_t display_buf_size = sizeof(DISPLAY_buffer)-1;                        //-1 because we have to subtract the starting command 0x40
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

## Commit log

2022-05-17 First commit (in this repo)
    [Schematico.brd, Schematico.sch, Schematico2.brd]
2022-05-18 OLED Measurement interface finished
    [Schematico.brd, Schematico2.brd]
2022-05-23 Schematic update and globals for EEPROM
    [Schematico.brd]
2022-05-25 Removed TIA calibration and updated real time graph
2022-05-25 Strip pins PCB
    [STRIP pins.brd, STRIP pins.sch]
2022-05-27 First code merge
    [STRIP pins.brd]
2022-05-27 Added 10 samples MA filter
2022-06-08 Psoc switch case merged
2022-06-15 Addede Battery lvl monitor and timer
2022-06-21 OLED Screen switched to GUI
2022-06-22 Look up table and CA initial potential
    [Look up table.xlsx]
2022-06-22 Added calibration curve and result display
2022-06-22 Look up table
    [Look up table.xlsx, dataframe.csv]
2022-06-29 Case stl
    [Case_ETBL v25.stl, Copertura case ETBL v15.stl, Glucometer_clip v12.stl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]
2022-07-06 Assembled case, new calibr data
    [Look up table.xlsx]
2022-07-07 New calibration and presentation
    [Look up table.xlsx]
2022-07-20 Final push
    [Look up table.xlsx]

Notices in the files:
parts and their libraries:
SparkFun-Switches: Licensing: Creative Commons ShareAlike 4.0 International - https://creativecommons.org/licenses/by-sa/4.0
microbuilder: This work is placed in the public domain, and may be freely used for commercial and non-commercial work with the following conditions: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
